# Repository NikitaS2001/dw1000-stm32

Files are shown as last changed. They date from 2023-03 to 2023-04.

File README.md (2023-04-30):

# Дальномерный радиомаяк на базе DW1000

## Описание

Проект представляет собой дальномерную систему на основе широкополосных модулей DW1000. Система реализована на базе алгоритма DS-TWR (Double-sided Two-Way Ranging). В системе расстояние рассчитывается между модулем A (TAG-модуль) и модулем B (ANCHOR-модуль). TAG модуль выполняет поллинг ANCHOR модулей и инициирует TWR алгоритм с каждым найденным ANCHOR-модулем в зоне действия.

## Оборудование

- [NodeMCU-BU01 UWB](https://aliexpress.ru/item/1005001571575318.html)
- [Модуль питания 18650](https://aliexpress.ru/item/1005002567437294.html)
- USB-UART конвертер

## Зависимости

- [MDK-ARM Professional (V5)](https://www.keil.com/demo/eval/arm.htm)

## Требуемое ПО

- uVision v5.38
- [STM Flash Loader Demo](https://www.st.com/en/development-tools/flasher-stm32.html#get-software)
- [PuTTY CR/LF](https://www.grzegorz.net/pliki/putty-crlf.zip)

## Сборка проекта

1. Установите MDK-ARM Professional (Lite версия не сможет собрать проект).
2. Установите uVision v5.38.
3. Склонируйте этот репозиторий на свой компьютер.
4. Откройте проект в uVision.
5. Выберите требуемый Target сборки (**TAG** или **ANCHOR**) и нажмите кнопку **Build (F7)**.
6. Собранная прошивка появится в директории **Build** ( и **dwm1000-tag.hex**).
   - **dwm1000-tag.hex** - для Target **TAG**
   - **dwm1000-anchor.hex** - для Target **ANCHOR**

## Прошивка модулей

Если нет возможности собрать проект вручную - актуальные прошивки можно найти в последнем релизе в репозитории.
Для загрузки прошивки выполните следующие шаги (для Windows):

1. Подключите BIT0 на плате модуля к питанию ([пример](https://imgur.com/a/wGIee8n)).
2. Подключите USB-UART конвертер к пинам UART0 на плате модуля ([схема](https://imgur.com/a/axm2B0i)).
3. Подключите USB-UART конвертер к USB порту на ПК.
4. Запустите **STM Flash Loader Demo** и выберите нужный COM порт в настройках UART (номер нужного порта можно узнать в диспетчере устройств Windows), остальные настройки менять не нужно ([пример настроек](https://imgur.com/a/PkMRx6a)).
5. Нажмите на кнопку *Next*. Если появляется ошибка *Cannot open the com port* - скорее всего указан не верный COM порт, также можно попробовать перезапустить модуль нажатием на кнопку [*Reset*](https://imgur.com/a/UnVmjwr).
6. На следующей вкладке (*Target is readable*) нажмите *Next*.
7. Убедитесь, что устройство (*Target*) выбрано [верно](https://imgur.com/a/uEidQcN) и нажмите *Next*.
8. Выберите нужный файл с прошивкой, выберите вариант *Erase necessary pages* (рекомендуется также включить верификацию *Verify after download*) [пример](https://imgur.com/a/cx4S0in).
9. Нажмите *Next* и дождитесь [окончания процесса загрузки прошивки](https://imgur.com/a/233zFzv). Далее можно нажать *Close*. При возникновении ошибок, например, при верификации, повторите процесс прошивки, начиная с пункта 4.

## Работа с модулями и настройка

После прошивки модуля необходимо произвести настройку - указать идентификатор модуля. Каждый модуль должен иметь свой уникальный идентификатор (целое число от 0 до 65535), чтобы он мог обозначить себя в системе коммуникации. На текущей версии системы TAG-модуль должен иметь идентификатор 0, ANCHOR-модули - идентификаторы от 1 до 10 включительно (остальные идентификаторы на данный момент не используются).

Настроить модуль можно, используя USB-UART конвертер и любой удобный клиент для работы через последовательный порт с поддержкой CR/LF окончания строки (например, [PuTTY](https://www.grzegorz.net/pliki/putty-crlf.zip), при этом в настройках Terminal/Keyboard для *The Enter key* должно быть выбрано [*CR LF*](https://imgur.com/a/BsUUB0w)).

Подключитесь через клиент последовательного порта к COM порту, соединённому с платой модуля через USB-UART конвертер и введите команду ***device_id set 0*** (для *TAG*-модуля) или ***device_id set \<id\>*** (для *ANCHOR*-модуля, без кавычек, *id = [1; 10]*). В ответ должно появиться сообщение *Device ID is set to '\<id\>'* ([пример](https://imgur.com/a/QvDkmbL)). Перезапустите модуль используя команду ***reset*** или кнопку *Reset* на плате.

После правильной установки ID модули готовы к работе.

## Размещение модулей

Для удобства размещения модулей в пространстве был разработан специальный корпус, совместимый с платами UWB модулей и модулями питания ([Модуль питания 18650](https://aliexpress.ru/item/1005002567437294.html)). Корпус можно найти в данном репозитории в виде STL-файлов и распечатать самостоятельно на 3D-принтере.

Предусмотрено 2 варианта размещения модулей:

- на горизонтальной плоскости;
- на вертикальных стойках.

Модели для сборки [основного корпуса](https://imgur.com/a/3Poopat):

- [bottomCase.STL](3D/bottomCase.STL) - нижняя крышка корпуса;
- [topCase.STL](3D/bottomCase.STL) - тело корпуса.

Модели для сборки [крепления](https://imgur.com/a/95MaVy1) для вертикальной стойки корпуса:

- [postBindBottom.STL](3D/postBindBottom.STL) - нижняя часть крепления (крепится к стойке);
- [postBindTop.STL](3D/postBindTop.STL) - верхняя часть крепления (крепится к основному корпусу).

## Подключение к внешним устройствам

TAG-модули могут быть подключены к другим устройствам (например, Raspberry) в качестве периферии, эти устройства могут получать данные о расстояниях до ANCHOR-модулей. Данные публикуются TAG-модулем с использованием протокола *ROSSERIAL* в топик '*dwm1000/beacon_data*' (тип сообщения [*BeaconDataArray*](https://github.com/NikitaS2001/dwm1000_pose/blob/main/msg/BeaconDataArray.msg)). Данные могут быть получены через интерфейс UART2 путём подключения к [соответствующим пинам на плате](https://imgur.com/a/1x2JMcx) (*Baudrate = 57600*).

Таким образом, дальномерная система может быть встроена в более широкие системы, например, системы позиционирования.

Пакет ROS с реализацией алгоритма позиционирования на основе трилатерации с использованием данной системы: https://github.com/NikitaS2001/dwm1000_pose.

## Авторы

Проект создан в рамках конкурса проектов [CopterHack-2023](https://github.com/CopterExpress/clover/blob/master/docs/ru/copterhack2023.md), команда **C305**.

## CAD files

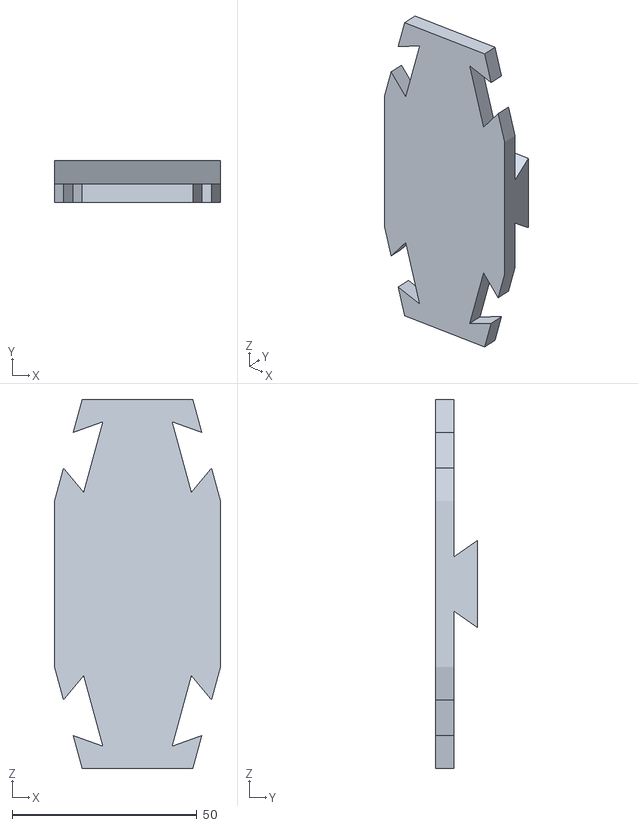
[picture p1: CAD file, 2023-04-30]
3D/downCaseForMainBeacon_1.STL
45.0 x 11.4 x 100.0

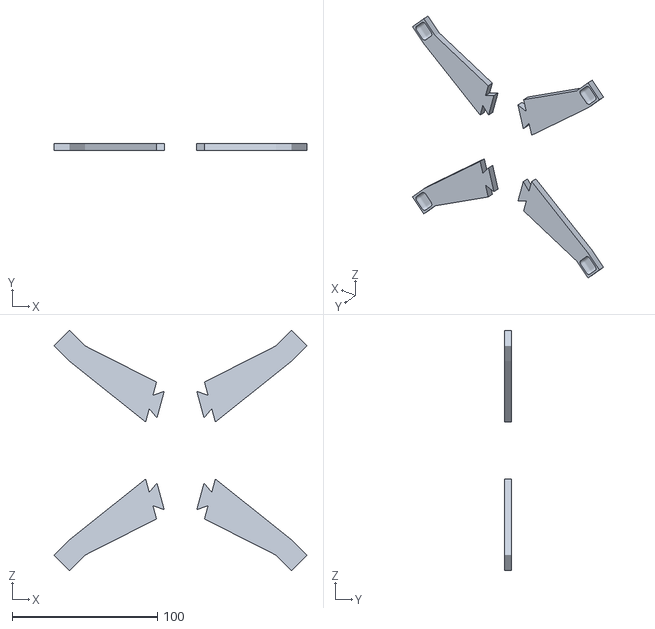
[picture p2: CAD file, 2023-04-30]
3D/downCaseForMainBeacon_2.STL
174.2 x 5.00 x 165.5

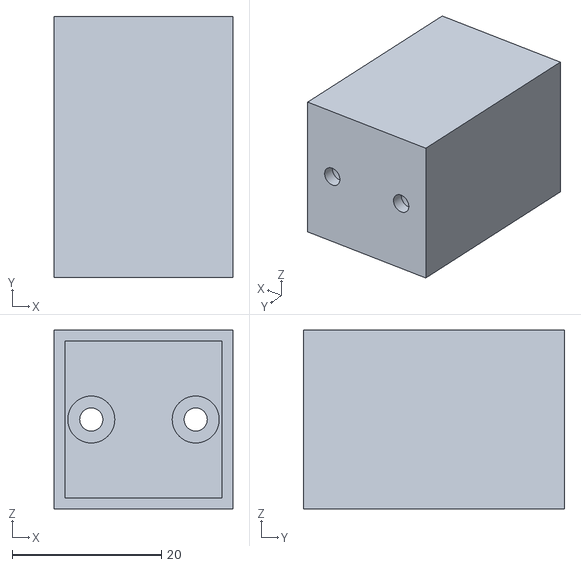
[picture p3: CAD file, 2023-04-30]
3D/postBindBottom.STL
24.0 x 35.0 x 24.0

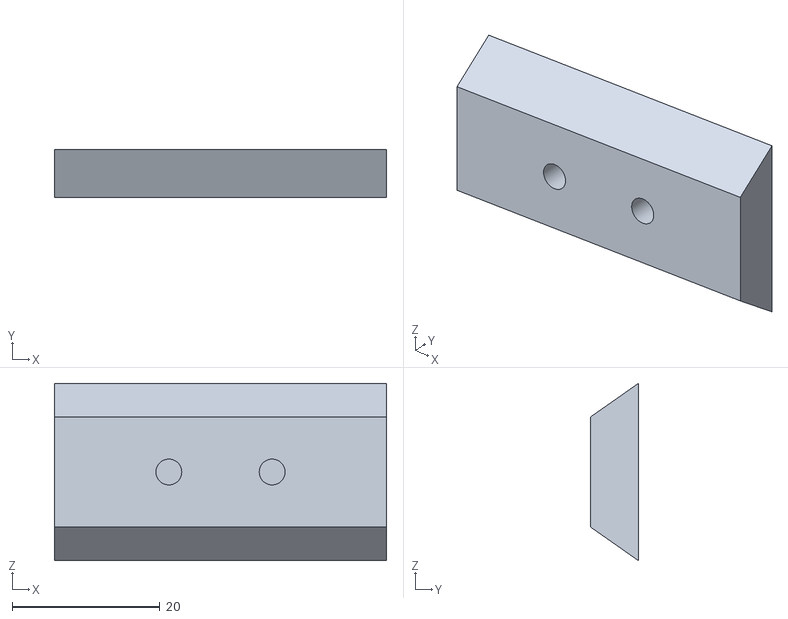
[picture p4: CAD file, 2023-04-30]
3D/postBindTop.STL
45.0 x 6.45 x 24.0

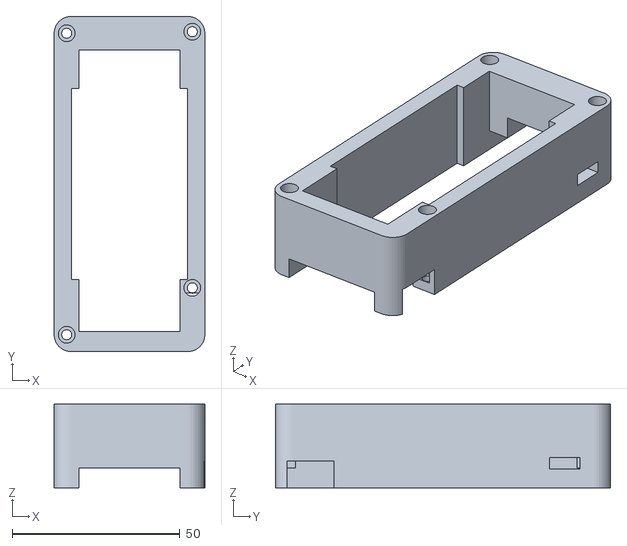
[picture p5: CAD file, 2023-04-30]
3D/topCase.STL
45.0 x 100.0 x 25.0

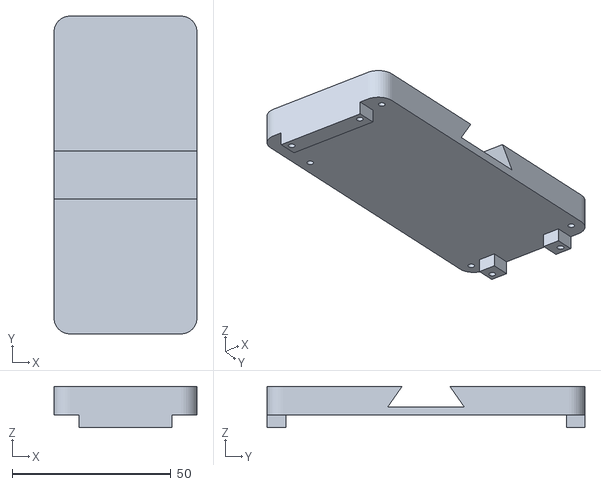
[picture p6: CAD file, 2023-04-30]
3D/bottomCase.STL
45.0 x 100.0 x 13.0

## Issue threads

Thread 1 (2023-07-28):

Вопрос по работе с модулем UWB

lch1204, 2023-07-28:
Добрый день! Можно ли более подробно узнать про ваш опыт работы с данным модулем? Просто мы уже около месяца пытаемся заставить его работать, чтобы найти расстояние между двумя маяками, но сталкиваемся с проблемами. Можете поделиться, какие результаты при работе с данным модулем вы получали. Смогли ли найти расстояние, какова была максимальная дистанция. Надеюсь на ответ

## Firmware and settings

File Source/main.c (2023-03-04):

#include "comm/comm.h"

#include "kalman/kalman.h"
#include "math/vector.h"
#include "shell/shell.h"

#include "at24c16/AT24C02.h"
#include "dwm1000/dwm1000.h"
#include "memory/flash.h"

#include "deca_lib/deca_device_api.h"
#include "deca_lib/deca_port.h"
#include "deca_lib/deca_regs.h"

#include <FreeRTOS.h>
#include <task.h>
#include <queue.h>

#include <stm32f10x.h>
#include <stm32_eval.h>

#include <math.h>
#include <stdio.h>
#include <string.h>

uint8 SWITCH_DIS = 0;

extern char dist_str[16];
extern uint8_t TAG_ID;
extern uint8_t MASTER_TAG;
extern uint8_t SLAVE_TAG_START_INDEX;
extern uint8_t ANCHOR_IND; 
extern uint8_t ANCHOR_IND; 
extern uint8 Semaphore[MAX_SLAVE_TAG];

vec3d tag_best_solution;
int Anthordistance[ANCHOR_MAX_NUM];

int Anthordistance_count[ANCHOR_MAX_NUM];

int ANCHOR_REFRESH_COUNT_set=5;
#define ANCHOR_REFRESH_COUNT ANCHOR_REFRESH_COUNT_set


void dwt_dumpregisters(char *str, size_t strSize)
{
    uint32 reg = 0;
    uint8 buff[5];
    int i;
    int cnt ;

    //reg 0x24
    for(i=0; i<=12; i+=4)
    {
        reg = dwt_read32bitoffsetreg(0x24,i) ;
        str += cnt = sprintf(str,"reg[%02X:%02X]=%08X",0x24,i,reg) ;
        str += cnt = sprintf(str,"\n") ;
    }

    //reg 0x27
    for(i=0; i<=44; i+=4)
    {
        reg = dwt_read32bitoffsetreg(0x27,i) ;
        str += cnt = sprintf(str,"reg[%02X:%02X]=%08X",0x27,i,reg) ;
        str += cnt = sprintf(str,"\n") ;
    }

    //reg 0x28
    for(i=0; i<=64; i+=4)
    {
        reg = dwt_read32bitoffsetreg(0x28,i) ;
        str += cnt = sprintf(str,"reg[%02X:%02X]=%08X",0x28,i,reg) ;
        str += cnt = sprintf(str,"\n") ;
    }

    //reg 0x2A
    for(i=0; i<20; i+=4)
    {
        reg = dwt_read32bitoffsetreg(0x2A,i) ;
        str += cnt = sprintf(str,"reg[%02X:%02X]=%08X",0x2A,i,reg) ;
        str += cnt = sprintf(str,"\n") ;
    }

    //reg 0x2B
    for(i=0; i<24; i+=4)
    {
        reg = dwt_read32bitoffsetreg(0x2B,i) ;
        str += cnt = sprintf(str,"reg[%02X:%02X]=%08X",0x2B,i,reg) ;
        str += cnt = sprintf(str,"\n") ;
    }

    //reg 0x2f
    for(i=0; i<40; i+=4)
    {
        reg = dwt_read32bitoffsetreg(0x2f,i) ;
        str += cnt = sprintf(str,"reg[%02X:%02X]=%08X",0x2f,i,reg) ;
        str += cnt = sprintf(str,"\n") ;
    }

    //reg 0x31
    for(i=0; i<84; i+=4)
    {
        reg = dwt_read32bitoffsetreg(0x31,i) ;
        str += cnt = sprintf(str,"reg[%02X:%02X]=%08X",0x31,i,reg) ;
        str += cnt = sprintf(str,"\n") ;
    }

    //reg 0x36 = PMSC_ID
    for(i=0; i<=48; i+=4)
    {
        reg = dwt_read32bitoffsetreg(0x36,i) ;
        str += cnt = sprintf(str,"reg[%02X:%02X]=%08X",0x36,i,reg) ;
        str += cnt = sprintf(str,"\n") ;
    }
}

void Anchor_Array_Init(void)
{
    int anchor_index = 0;
    for(anchor_index = 0; anchor_index < ANCHOR_MAX_NUM; anchor_index++)
    {
        Anthordistance[anchor_index] = 0;
        Anthordistance_count[anchor_index] = 0;
    }
}

void Semaphore_Init(void)
{
    int tag_index = 0 ;
    for(tag_index = 0; tag_index <MAX_SLAVE_TAG; tag_index++)
    {
        Semaphore[tag_index]  = 0;
    }
}

int Sum_Tag_Semaphore_request(void)
{
    int tag_index = 0 ;
    int sum_request = 0;
    for(tag_index = SLAVE_TAG_START_INDEX; tag_index <MAX_SLAVE_TAG; tag_index++)
    {
        sum_request+=Semaphore[tag_index];
    }
    return sum_request;
}


void Tag_Measure_Dis(void)
{
    printf("Tag_Measure_Dis");

    uint8 dest_anthor = 0,frame_len = 0;
    float final_distance = 0;
    frame_seq_nb=0;

    for(dest_anthor = 0 ;  dest_anthor<ANCHOR_MAX_NUM; dest_anthor++)
    {
        dwt_setrxaftertxdelay(POLL_TX_TO_RESP_RX_DLY_UUS);
        dwt_setrxtimeout(RESP_RX_TIMEOUT_UUS);
    
        /* Write frame data to DW1000 and prepare transmission. */
        tx_poll_msg[ALL_MSG_SN_IDX] = frame_seq_nb;
        tx_poll_msg[ALL_MSG_TAG_IDX] = TAG_ID;
        dwt_writetxdata(sizeof(tx_poll_msg), tx_poll_msg, 0);
        dwt_writetxfctrl(sizeof(tx_poll_msg), 0);

        /* Start transmission, indicating that a response is expected so that reception is enabled automatically after the frame is sent and the delay
         * set by dwt_setrxaftertxdelay() has elapsed. */
        dwt_starttx(DWT_START_TX_IMMEDIATE| DWT_RESPONSE_EXPECTED);

        //GPIO_SetBits(GPIOA,GPIO_Pin_2);
        //TODO
        dwt_rxenable(0);
        uint32 tick1=portGetTickCount();
        /* We assume that the transmission is achieved correctly, poll for reception of a frame or error/timeout. */
        while (!((status_reg = dwt_read32bitreg(SYS_STATUS_ID)) & (SYS_STATUS_RXFCG | SYS_STATUS_ALL_RX_ERR)))
        {
            if((portGetTickCount() - tick1) > 350)
            {
                break;
            }

        };

        GPIO_SetBits(GPIOA, GPIO_Pin_1);

        if (status_reg & SYS_STATUS_RXFCG)
        {
            /* Clear good RX frame event and TX frame sent in the DW1000 status register. */
            dwt_write32bitreg(SYS_STATUS_ID, SYS_STATUS_RXFCG | SYS_STATUS_TXFRS);

            /* A frame has been received, read it into the local buffer. */
            frame_len = dwt_read32bitreg(RX_FINFO_ID) & RX_FINFO_RXFLEN_MASK;
            if (frame_len <= RX_BUF_LEN)
            {
                dwt_readrxdata(rx_buffer, frame_len, 0);
            }

            if(rx_buffer[ALL_MSG_TAG_IDX] != TAG_ID)
            {
                continue;
            }

            rx_buffer[ALL_MSG_TAG_IDX] = 0;

            /* As the sequence number field of the frame is not relevant, it is cleared to simplify the validation of the frame. */
            rx_buffer[ALL_MSG_SN_IDX] = 0;

            if (memcmp(rx_buffer, rx_resp_msg, ALL_MSG_COMMON_LEN) == 0)
            {
                uint32 final_tx_time;

                /* Retrieve poll transmission and response reception timestamp. */
                poll_tx_ts = get_tx_timestamp_u64();
                resp_rx_ts = get_rx_timestamp_u64();

                /* Compute final message transmission time. */
                final_tx_time = (resp_rx_ts + (RESP_RX_TO_FINAL_TX_DLY_UUS * UUS_TO_DWT_TIME)) >> 8;
                dwt_setdelayedtrxtime(final_tx_time);

                /* Final TX timestamp is the transmission time we programmed plus the TX antenna delay. */
                final_tx_ts = (((uint64)(final_tx_time & 0xFFFFFFFE)) << 8) + TX_ANT_DLY;

                /* Write all timestamps in the final message. See NOTE 10 below. */
                final_msg_set_ts(&tx_final_msg[FINAL_MSG_POLL_TX_TS_IDX], poll_tx_ts);
                final_msg_set_ts(&tx_final_msg[FINAL_MSG_RESP_RX_TS_IDX], resp_rx_ts);
                final_msg_set_ts(&tx_final_msg[FINAL_MSG_FINAL_TX_TS_IDX], final_tx_ts);

                /* Write and send final message. */
                tx_final_msg[ALL_MSG_SN_IDX] = frame_seq_nb;
                tx_final_msg[ALL_MSG_TAG_IDX] = TAG_ID;
                dwt_writetxdata(sizeof(tx_final_msg), tx_final_msg, 0);
                dwt_writetxfctrl(sizeof(tx_final_msg), 0);

                //TODO maybe need longer time
                //dwt_setrxaftertxdelay(POLL_TX_TO_RESP_RX_DLY_UUS);
                //dwt_setrxtimeout(RESP_RX_TIMEOUT_UUS*2);
                dwt_starttx(DWT_START_TX_DELAYED | DWT_RESPONSE_EXPECTED );

                while (!((status_reg = dwt_read32bitreg(SYS_STATUS_ID)) & (SYS_STATUS_RXFCG | SYS_STATUS_ALL_RX_ERR)))
                { 
                    if((portGetTickCount() - tick1) > 500)
                    {
                        break;
                    }
                }

                /* Increment frame sequence number after transmission of the poll message (modulo 256). */
                if (status_reg & SYS_STATUS_RXFCG)
                {
                    /* Clear good/fail RX frame event in the DW1000 status register. */
                    dwt_write32bitreg(SYS_STATUS_ID, SYS_STATUS_RXFCG | SYS_STATUS_TXFRS);
                    /* A frame has been received, read it into the local buffer. */
                    frame_len = dwt_read32bitreg(RX_FINFO_ID) & RX_FINFO_RXFLEN_MASK;
                    if (frame_len <= RX_BUF_LEN)
                    {
                        dwt_readrxdata(rx_buffer, frame_len, 0);
                    }

                    if(rx_buffer[ALL_MSG_TAG_IDX] != TAG_ID)
                        continue;
                    rx_buffer[ALL_MSG_TAG_IDX] = 0;

                    /*As the sequence number field of the frame is not relevant, it is cleared to simplify the validation of the frame. */
                    rx_buffer[ALL_MSG_SN_IDX] = 0;

                    if (memcmp(rx_buffer, distance_msg, ALL_MSG_COMMON_LEN) == 0)
                    {
                        // final_distance = rx_buffer[10] + (float)rx_buffer[11]/100;
                        Anthordistance[rx_buffer[12]] +=(rx_buffer[10]*1000 + rx_buffer[11]*10);
                        Anthordistance_count[rx_buffer[12]] ++;
                        {
                            int Anchor_Index = 0;
                            while(Anchor_Index < ANCHOR_MAX_NUM)
                            {
                                if(Anthordistance_count[Anchor_Index] >=ANCHOR_REFRESH_COUNT )
                                {
                                    distance_mange();
                                    Anchor_Index = 0;

                                    //clear all
                                    while(Anchor_Index < ANCHOR_MAX_NUM)
                                    {
                                        Anthordistance_count[Anchor_Index] = 0;
                                        Anthordistance[Anchor_Index] = 0;
                                        Anchor_Index++;
                                    }
                                    break;
                                }
                                Anchor_Index++;
                            }
                        }
                    }
                }
                else
                {
                    /* Clear RX error events in the DW1000 status register. */
                    dwt_write32bitreg(SYS_STATUS_ID, SYS_STATUS_ALL_RX_ERR);
                }
            }
        }
        else
        {
            /* Clear RX error events in the DW1000 status register. */
            // sprintf(dist_str, "%08x",status_reg);
            dwt_write32bitreg(SYS_STATUS_ID, SYS_STATUS_ALL_RX_ERR);
        }
        /* Execute a delay between ranging exchanges. */
        // vTaskDelay(RNG_DELAY_MS);
        frame_seq_nb++;
    }

}

double final_distance =  0;

void vMainTask(void *pvParameters)
{
    uint8 anthor_index = 0;
    uint8 tag_index = 0;

    uint8 Semaphore_Enable = 0 ;
    uint8 Waiting_TAG_Release_Semaphore = 0;
    int8 frame_len = 0;

    printf("Initializing dwm1000...\r\n");

    /* Reset and initialise DW1000.
     * For initialisation, DW1000 clocks must be temporarily set to crystal speed. After initialisation SPI rate can be increased for optimum
     * performance. */

    reset_DW1000(); /* Target specific drive of RSTn line into DW1000 low for a period. */
    spi_set_rate_low();


    if(dwt_initialise(DWT_LOADUCODE) == -1)
    {
        printf("dwm1000 init is failed!\r\n");

        // Blink LED when init is failed
        while (1)
        {
            GPIO_SetBits(GPIOC, GPIO_Pin_13);
            vTaskDelay(1000);

            GPIO_ResetBits(GPIOC, GPIO_Pin_13);
            vTaskDelay(1000);
        }
    }

    spi_set_rate_high();

    /* Configure DW1000. */
    dwt_configure(&config);
    dwt_setleds(1);

    /* Apply default antenna delay value. */
    dwt_setrxantennadelay(RX_ANT_DLY);
    dwt_settxantennadelay(TX_ANT_DLY);

    printf("Init pass!\r\n");

    int rx_ant_delay =32880;
    int index = 0 ;

    typedef struct
    {
        uint16_t ANCHOR_TAG;      //{1 anchor 0 tag}
        uint16_t ID;      //{1 anchor 0 tag}
    
    }UserSet;
    UserSet UserSetNow;
    uint16_t buff[3]={1,0,0xff};
    FLASH_ReadMoreData(USER_FLASH_BASE,buff,3);
    if(buff[0]==1)
    {
        UserSetNow.ANCHOR_TAG=1;
    }
    else if(buff[0]==0)
    {
        UserSetNow.ANCHOR_TAG=0;
    }
    else
    {
        UserSetNow.ANCHOR_TAG=1;
    }

    if(UserSetNow.ANCHOR_TAG==1)
    {
        if(buff[1]>=0 && buff[1]<=255)
        {
            UserSetNow.ID=buff[1];
            ANCHOR_IND=UserSetNow.ID;
        }
        printf("device:anchor ID:%d\r\n",ANCHOR_IND);

        Anchor_Array_Init();

        /* Loop forever initiating ranging exchanges. */
        //KalMan_PramInit();
        ANTHOR_MEASURE();
    }

    if(UserSetNow.ANCHOR_TAG==0)
    {
        if(buff[1]>=0 && buff[1]<=255)
        {
            UserSetNow.ID=buff[1];
            TAG_ID=UserSetNow.ID;
            MASTER_TAG=TAG_ID;
        }

        printf("device:TAG ID:%d\r\n",UserSetNow.ID);

        /* Set expected response's delay and timeout.
        * As this example only handles one incoming frame with always the same delay and timeout, those values can be set here once for all. */
        dwt_setrxaftertxdelay(POLL_TX_TO_RESP_RX_DLY_UUS);
        dwt_setrxtimeout(RESP_RX_TIMEOUT_UUS);
        
        if(TAG_ID ==  MASTER_TAG)
        {
            Semaphore_Enable = 1 ;
            Semaphore_Init();
            Waiting_TAG_Release_Semaphore = 0;
        }
        else
        {
            Semaphore_Enable = 0 ;
        }

        //Master TAG0
        TAG_MEASURE();
    }

    vTaskDelete(NULL);	
}

int main(void)
{
    /* Start with board specific hardware init. */
    peripherals_init();

    ShellInit();

    // Initializing ROS communication
    // CommInit();

    xTaskCreate(vMainTask, (signed char*)"MainTask", configMINIMAL_STACK_SIZE,
					NULL, tskIDLE_PRIORITY + 1, NULL);

    vTaskStartScheduler();
}

#define Filter_N 5  //max filter use in this system
const int Filter_D_set=5;
#define Filter_D Filter_D_set  //each filter contain "Filter_D" data
int Value_Buf[Filter_N][Filter_D]= {0};
int filter_index[Filter_N] = {0};
int filter(int input, int fliter_idx )
{
    char count = 0;
    int sum = 0;
    if(input > 0)
    {
        Value_Buf[fliter_idx][filter_index[fliter_idx]++]=input;
        if(filter_index[fliter_idx] == Filter_D) filter_index[fliter_idx] = 0;

        for(count = 0; count<Filter_D; count++)
        {
            sum += Value_Buf[fliter_idx][count];
        }
        return (int)(sum/Filter_D);
    }
    else
    {
        for(count = 0; count<Filter_D; count++)
        {
            sum += Value_Buf[fliter_idx][count];
        }
        return (int)(sum/Filter_D);
    }

}

static void distance_mange(void)
{
    {
        int Anchor_Index = 0;
        while(Anchor_Index < ANCHOR_MAX_NUM)
        {
            if(Anthordistance_count[Anchor_Index] > 0 )
            {
                Anthordistance[Anchor_Index] =filter((int)(Anthordistance[Anchor_Index]/Anthordistance_count[Anchor_Index]),Anchor_Index);
            }
            Anchor_Index++;
        }
    }

    compute_angle_send_to_anthor0(Anthordistance[0], Anthordistance[1],Anthordistance[2]);


    for(int j=0;j<ANCHOR_MAX_NUM;j++)
    {
        if(Anthordistance_count[j]>0)
        {
            sprintf(dist_str, "an%d:%3.2fm",j,(float)Anthordistance[j]/1000);
            printf("%s\r\n",dist_str);
        }
    }
}

//**************************************************************//
//distance1 anthor0 <--> TAG  mm
//distance2 anthor1 <--> TAG  mm
//distance3 anthor2 <--> TAG  mm
//**************************************************************//
static void compute_angle_send_to_anthor0(int distance1, int distance2,int distance3)
{
    static int framenum = 0 ;

    //location
    {
        uint8 len = 0;
        angle_msg[LOCATION_FLAG_IDX] = 1;

        angle_msg[LOCATION_INFO_START_IDX + (len++)] = 'm';
        angle_msg[LOCATION_INFO_START_IDX + (len++)] = 'r';

        angle_msg[LOCATION_INFO_START_IDX + (len++)] = 0x02;
        angle_msg[LOCATION_INFO_START_IDX + (len++)] = TAG_ID;//TAG ID

        angle_msg[LOCATION_INFO_START_IDX + (len++)] = (uint8)(framenum&0xFF);
        angle_msg[LOCATION_INFO_START_IDX + (len++)] = (uint8)((framenum>>8)&0xFF);

        angle_msg[LOCATION_INFO_START_IDX + (len++)] = (uint8)((distance1/10)&0xFF);
        angle_msg[LOCATION_INFO_START_IDX + (len++)] = (uint8)((distance1/10 >>8)&0xFF);

        angle_msg[LOCATION_INFO_START_IDX + (len++)] =  (uint8)((distance2/10)&0xFF);
        angle_msg[LOCATION_INFO_START_IDX + (len++)] =  (uint8)((distance2/10 >>8)&0xFF);
        angle_msg[LOCATION_INFO_START_IDX + (len++)] =  (uint8)((distance3/10)&0xFF);
        angle_msg[LOCATION_INFO_START_IDX + (len++)] =  (uint8)((distance3/10 >>8)&0xFF);
        angle_msg[LOCATION_INFO_START_IDX + (len++)] = (uint8)((distance1/10)&0xFF);
        angle_msg[LOCATION_INFO_START_IDX + (len++)] = (uint8)((distance1/10 >>8)&0xFF);
        angle_msg[LOCATION_INFO_START_IDX + (len++)] = '\n';
        angle_msg[LOCATION_INFO_START_IDX + (len++)] = '\r';


        angle_msg[LOCATION_INFO_LEN_IDX] = len;
        //MAX LEN
        if(LOCATION_INFO_START_IDX + len -2 >ANGLE_MSG_MAX_LEN)
        {
            while(1);//toggle LED
        }
        //USART_puts((char*)dist_str,16);

    }

    //only anthor0 recive angle message
    angle_msg[ALL_MSG_SN_IDX] = framenum;
    angle_msg[ALL_MSG_TAG_IDX] = TAG_ID;

    dwt_writetxdata(sizeof(angle_msg), angle_msg, 0);
    dwt_writetxfctrl(sizeof(angle_msg), 0);

    /* Start transmission, indicating that a response is expected so that reception is enabled automatically after the frame is sent and the delay
     * set by dwt_setrxaftertxdelay() has elapsed. */
    dwt_starttx(DWT_START_TX_IMMEDIATE );

    while (!(dwt_read32bitreg(SYS_STATUS_ID) & SYS_STATUS_TXFRS))
    { };

    framenum++;
}

static void final_msg_set_ts(uint8 *ts_field, uint64 ts)
{
    int i;
    for (i = 0; i < FINAL_MSG_TS_LEN; i++)
    {
        ts_field[i] = (uint8) ts;
        ts >>= 8;
    }
}

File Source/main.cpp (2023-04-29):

#include "shell/shell.h"
#include "telem/telem.h"
#include "uwb/uwb.h"

#include "dwm1000/dwm1000.h"

#include "deca_lib/deca_device_api.h"
#include "deca_lib/deca_port.h"

#include <FreeRTOS.h>
#include <task.h>

#include <stdio.h>

void MainTask(void* pvParameter)
{
    /* Start with board specific hardware init. */
    peripherals_init();

    printf("Initializing DWM1000...\r\n");

    /* Reset and initialise DW1000.
     * For initialisation, DW1000 clocks must be temporarily set to crystal speed. After initialisation SPI rate can be increased for optimum
     * performance. */

    reset_DW1000();

    /* Target specific drive of RSTn line into DW1000 low for a period. */
    spi_set_rate_low();

    if (dwt_initialise(DWT_LOADUCODE) == -1)
    {
        printf("DWM1000 init is failed!\r\n");

        // Blink LED when init is failed
        while (true)
        {
            GPIO_SetBits(GPIOC, GPIO_Pin_13);
            vTaskDelay(1000 / portTICK_PERIOD_MS);

            GPIO_ResetBits(GPIOC, GPIO_Pin_13);
            vTaskDelay(1000 / portTICK_PERIOD_MS);
        }
    }

    spi_set_rate_high();

    /* Configure DW1000. */
    dwt_configure(&config);
    dwt_setleds(1);

    printf("Init pass!\r\n");

    ShellInit();

    xTaskCreate(
        UwbTask,
        "UwbTask",
        configMINIMAL_STACK_SIZE * 10,
        NULL,
        tskIDLE_PRIORITY + 1,
        NULL);

#ifndef BEACON

    xTaskCreate(
        TelemTask,
        "TelemTask",
        configMINIMAL_STACK_SIZE,
        NULL,
        tskIDLE_PRIORITY + 1,
        NULL);

#endif

    vTaskDelete( NULL );
}

int main(void)
{
    xTaskCreate(
        MainTask,
        "MainTask",
        configMINIMAL_STACK_SIZE,
        NULL,
        tskIDLE_PRIORITY + 1,
        NULL);

    vTaskStartScheduler();
}

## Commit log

2023-02-17 Removed led, removed trilateration
2023-02-27 Added USART2 init to STM32Hardware
2023-03-13 Shell print improvements
2023-03-25 Removed kalman filter
2023-04-29 Adjusted antenna delays
2023-04-30 Updated readme, added STL models
    [bottomCase.STL, downCaseForMainBeacon_1.STL, downCaseForMainBeacon_2.STL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]
